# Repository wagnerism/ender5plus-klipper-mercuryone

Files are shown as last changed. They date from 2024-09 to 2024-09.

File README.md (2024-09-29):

# ender5plus-klipper-mercuryone
Klipper configurations for Ender 5 Plus with MKS Robin Nano v3 and the Mercury One CoreXY mod.

# Future changes
* Install Rapido UHF hotend<br>
https://trianglelab.net/products/rapido-hotend-20?VariantsId=11312
* Install filament runout detector direct on the orbiter extruder<br>
https://trianglelab.net/products/orbiter-v2-filament-sensor?VariantsId=10610
* Hydra 3-point bed mod
  * https://docs.zerog.one/manual/build/hydra/introduction
  * second MCU instead of replacing the main board with one that has more stepper drivers

# References

## Hardware I Used

| **Item** | **Name** | **Link** | **Note** |
|-|-|-|-|
| **Base Printer** | Ender 5 Plus| https://www.creality.com/products/ender-5-plus-3d-printer||
| **CoreXY Mod** | Mercury One Zero G| https://docs.zerog.one/||
| **Mainboard** | MKS Robin Nano V3.1| https://github.com/makerbase-mks/MKS-Robin-Nano-V3| |
| **Probe**| BTT Microprobe| https://github.com/bigtreetech/MicroProbe||
| **Hotend**| Triangle Lab Rapido HF| https://trianglelab.net/products/rapido-hotend?VariantsId=10027| Changing to Rapido UHF|
| **Extruder**| Triangle Lab Orbiter v2 | https://trianglelab.net/products/orbiter-extruder-v20%EF%BC%88black-gear%EF%BC%89 ||
| **Filament Sensor** | BTT Smart Filament Sensor | https://github.com/bigtreetech/smart-filament-detection-module | Changing to Orbiter detector|
| **E34M1**|EVA3 for Mercury One| https://jon-harper.github.io/E34M1/||
| **stepper motors**|Mercury One BOM|https://www.omc-stepperonline.com/e-series-nema-17-bipolar-55ncm-77-88oz-in-2a-42x48mm-4-wires-w-1m-cable-connector-17he19-2004s||

## My Contribution
STL file: Mount the BTT Microprobe on the E34M1 head (uses M3 bolts and nuts)

## Software / Documentation
| **Name** | **Link** | **Note** |
|---|---|---|
| **KIAUH** | https://github.com/dw-0/kiauh?tab=readme-ov-file||
| **TMC Autotuning** | https://github.com/andrewmcgr/klipper_tmc_autotuneGuide** ||
| **Ellis' Tuning Guide** | https://ellis3dp.com/Print-Tuning-Guide/||
| **Ellis' TEST_SPEED macro** | https://github.com/AndrewEllis93/Print-Tuning-Guide/blob/main/macros/TEST_SPEED.cfg  ||

# Custom configuration changes
Using the MKS Robin Nano's unused second extruder ports.

## Dual Z
The "hotend 1" stepper driver is being used for stepper_z1. Z_TILT_ADJUST requires that the stepper motors be connected a specific way.<br><br>With origin at the front-left corner:
* Connect the first/original stepper_z driver to the left-hand stepper motor.
* Connect the second/hotend1 stepper_z1 driver to the right-hand stepper motor.

## Fans
The Ender 5 Plus has three fans - hotend, part cooling, and controller. None of them are "always-on."

| **Connector**|**MCU Pin**| **Device** |
|---|---|----|
| FAN1 | PC14 | controller/case fan
| FAN2 | PB1 | hotend fan
| HE1 | PB0 | part cooling fan(s)

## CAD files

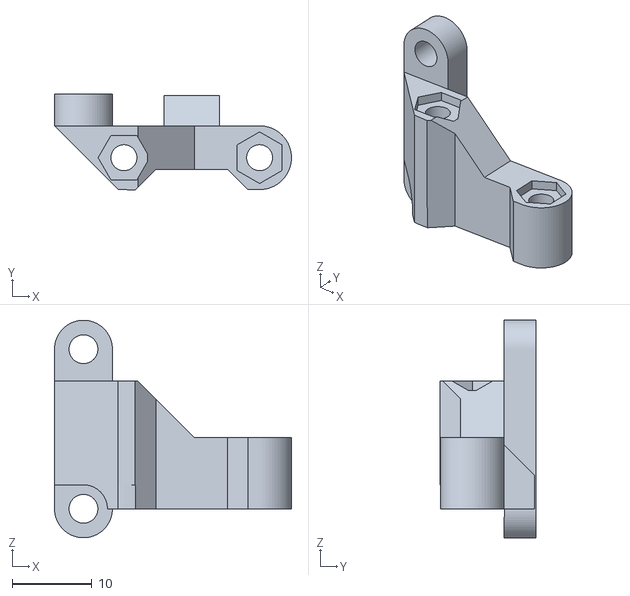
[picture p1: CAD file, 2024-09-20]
E34M1 MercuryOne BTT micro probe mount with Rapido HF.stl
29.7 x 12.1 x 27.3

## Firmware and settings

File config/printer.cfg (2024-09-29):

[include fluidd.cfg]
[include tuning/TEST_SPEED.cfg]
[include slicer_macros/orcaslicer.cfg]
[include macros.cfg]
#[include filament_sensor.cfg]
[include filament_macros.cfg]

[exclude_object]

# TODOs 
# camera
# beeper on PC5
# end print macro to retract, move to 0,0 , move z down some
# first layer https://ellis3dp.com/Print-Tuning-Guide/articles/first_layer_squish.html Z_OFFSET_APPLY_PROBE

[virtual_sdcard]
path: /home/rfwagner/printer_data/gcodes
on_error_gcode: CANCEL_PRINT
[mcu]
serial: /dev/serial/by-id/usb-Klipper_stm32f407xx_2C0043000950313154393520-if00

[display_status]
[pause_resume]

[printer]
kinematics: corexy
max_velocity: 800  
max_accel: 10000 
# minimum_cruise_ratio: 0.5
max_z_velocity: 5
max_z_accel: 100
square_corner_velocity: 5.0
# Enable arcs support
[gcode_arcs]
resolution: 0.1


[temperature_sensor MCU]
sensor_type: temperature_mcu
[temperature_sensor RPi]
sensor_type: temperature_host



[mcu rpi]
serial: /tmp/klipper_host_mcu

[adxl345]
cs_pin: rpi:None

[resonance_tester]
accel_chip: adxl345
probe_points:
    170, 170, 5  # an example



[input_shaper]
#shaper_freq_x: 53.4
#shaper_type_x: mzv
#shaper_freq_y: 48.0
#shaper_type_y: 3hump_ei



[autotune_tmc stepper_x]
motor: omc-17he19-2004s
#tuning_goal: silent  # default: auto=performance
##extra_hysteresis: 0  # up to 8, reduce hum/vib at low speeds
[stepper_x]
# StepperOnline 17HE19-2004S rated at 2.0A max
# https://www.omc-stepperonline.com/e-series-nema-17-bipolar-55ncm-77-88oz-in-2a-42x48mm-4-wires-w-1m-cable-connector-17he19-2004s
# max current 2.0A
step_pin: PE3
dir_pin: !PE2
enable_pin: !PE4
endstop_pin: !PA15
rotation_distance: 40
microsteps: 16
full_steps_per_rotation: 200
position_min: 0
position_endstop: 377 
position_max: 377
homing_speed: 125 #50
homing_retract_dist: 10
[tmc2209 stepper_x]
uart_pin: PD5
run_current: 1.13 # 1.13  # max current 2.0A https://docs.zerog.one/universal/klippercalculator
interpolate: true



[autotune_tmc stepper_y]
motor: omc-17he19-2004s
#tuning_goal: silent  # default: auto=performance
##extra_hysteresis: 0  # up to 8, reduce hum/vib at low speeds
[stepper_y]
# StepperOnline 17HE19-2004S rated at 2.0A max
step_pin: PE0
dir_pin: !PB9
enable_pin: !PE1
endstop_pin: !PD2
rotation_distance: 40
microsteps: 16
full_steps_per_rotation: 200 
position_min: 0
position_endstop: 348 
position_max: 353
homing_speed: 125 #50
homing_retract_dist: 10
[tmc2209 stepper_y]
uart_pin: PD7
run_current: 1.13 # 1.13  # max current 2.0A https://docs.zerog.one/universal/klippercalculator
interpolate: true



[autotune_tmc stepper_z]
motor: creality-42-34
tuning_goal: auto  # default auto=silent
[stepper_z]  # https://github.com/Klipper3d/klipper/blob/master/config/printer-creality-ender5plus-2019.cfg
# Creality 42-34 rated at 1.5A max
# left hand side
step_pin: PB5
dir_pin: !PB4
enable_pin: !PB8
microsteps: 16
rotation_distance: 4
endstop_pin: probe:z_virtual_endstop
position_max: 410
position_min: -10.0
homing_speed: 10.0
[tmc2209 stepper_z]
uart_pin: PD4
run_current: 0.75 # 0.85  # max current 1.5A https://docs.zerog.one/universal/klippercalculator
interpolate: true



[autotune_tmc stepper_z1]
motor: creality-42-34
tuning_goal: auto  # default auto=silent
[stepper_z1]
# Creality 42-34 rated at 1.5A
# right hand side
step_pin: PD15
dir_pin: !PA1 
enable_pin: !PA3 
microsteps: 16
rotation_distance: 4
[tmc2209 stepper_z1]
uart_pin: PD8
run_current: 0.75 # 0.85  # max current 1.5A https://docs.zerog.one/universal/klippercalculator
interpolate: true

[safe_z_home]
home_xy_position: 175,175
z_hop: 5

[z_tilt]
z_positions:    -19,165
                395,165
points:         31,174
                377,174
speed: 300

[screws_tilt_adjust]
screw1: 66,43
screw1_name: front_left
screw2: 358,43
screw2_name: front_right
screw3: 358,304
screw3_name: rear_right
screw4: 66,304
screw4_name: rear_left
screw_thread: CW-M3
speed: 500



[autotune_tmc extruder]
motor: ldo-36sth20-1004ahg
tuning_goal: performance  # default auto=silent
[extruder]
# orbiter extruder v2.0 LDO  https://trianglelab.net/u_file/2112/11/file/Orbiterv20FirmwareConfiguration-031c.pdf
# 690 steps/mm @ 16 micro-stepping
# motor current 1.2A peak or 0.85A RMS LDO-36STH20-1004AHG
# max accelleration 10000 mm/s2
# Triangle Lab Rapido HF
step_pin: PD6
dir_pin: !PD3
enable_pin: !PB3
microsteps: 16
full_steps_per_rotation: 200  # per TriangleLab doc
rotation_distance: 4.637  # per TriangleLab doc
nozzle_diameter: 0.600
filament_diameter: 1.750
max_extrude_only_distance: 500
max_extrude_only_velocity: 120
pressure_advance: 0.025
pressure_advance_smooth_time: 0.03
heater_pin: PE5
sensor_type: ATC Semitec 104NT-4-R025H42G
sensor_pin: PC1
#control: pid
#pid_Kp: 14.669
#pid_Ki: 0.572
#pid_Kd: 94.068
min_temp: 0
max_temp: 280
[tmc2209 extruder]
uart_pin: PD9
run_current: 0.85
hold_current: 0.100
sense_resistor: 0.11 
driver_TBL: 0
driver_HEND: 6
driver_HSTRT: 7
driver_TOFF: 4
interpolate: true



[heater_bed]
heater_pin: PA0
sensor_type: EPCOS 100K B57560G104F
sensor_pin: PC0
#control: pid
#pid_Kp: 325.10
#pid_Ki: 63.35
#pid_Kd: 417.10
min_temp: 0
max_temp: 130



[fan]  # print cooling fan
# originally pin: PC14   # fan1 without hardware PWM
pin: PB0  # "he1" repurposed connection
# yel/blu wires to head
[heater_fan heatbreak_cooling_fan]  
pin: PB1 # fan2 with hardware PWM
# red/blk wires to head
[controller_fan controller_fan]
pin: PC14  # "fan1" repurposed connection
stepper: stepper_x, stepper_y, stepper_z, stepper_z1, extruder
# red/blk wires to case

# fan testing configurations
#[fan_generic he1_PB0_printfan]
#pin: PB0  # yel/blu wires to head
## SET_FAN_SPEED FAN=he1_PB0_printfan SPEED=100

#[fan_generic fan2_PB1_heatbreak]
#pin:PB1  # red/blk wires to head
## SET_FAN_SPEED FAN=fan2_PB1_heatbreak SPEED=100

#[fan_generic fan1_PC14_controller]
#pin: PC14 # red/blk wires to case
## SET_FAN_SPEED FAN=fan1_PC14_controller SPEED=100


# https://github.com/bigtreetech/MicroProbe
[gcode_macro PROBE_DOWN]
gcode:
    SET_PIN PIN=probe_enable VALUE=1
[gcode_macro PROBE_UP]
gcode:
    SET_PIN PIN=probe_enable VALUE=0
[output_pin probe_enable]
pin: PA8  # Set to the control pin on your board
value: 0
[probe]
pin: ^!PC8  # for v2 microprobe
deactivate_on_each_sample: False
x_offset: -24
y_offset: -9
#z_offset: 2.05
samples: 2
samples_tolerance: 0.05
samples_tolerance_retries: 3
activate_gcode:
    PROBE_DOWN
    G4 P500
deactivate_gcode:
    PROBE_UP


[bed_mesh]
# 44,9 yields 68,18 at first point
# refers to probe location offset is -24, -9
speed: 500
horizontal_move_z: 2
mesh_min: 20, 0
mesh_max: 352, 321
probe_count: 7, 7
mesh_pps: 2, 2
algorithm: bicubic
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

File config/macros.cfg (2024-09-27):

[gcode_macro CALIBRATE_SHAPER]
gcode:  _CG28
        SHAPER_CALIBRATE

#[gcode_macro SAVE]
#gcode:  

[gcode_macro _CG28]
gcode:
    {% if "xyz" not in printer.toolhead.homed_axes %}
        G28
    {% endif %}

#https://ellis3dp.com/Print-Tuning-Guide/articles/index_useful_macros.html
[gcode_macro DUMP_VARIABLES]
gcode:
    {% set filter_name = params.NAME|default('')|string|lower %}
    {% set filter_value = params.VALUE|default('')|string|lower %}
    {% set show_cfg = params.SHOW_CFG|default(0)|int %}
    
    {% set out = [] %}

    {% for key1 in printer %}
        {% for key2 in printer[key1] %}
            {% if (show_cfg or not (key1|lower == 'configfile' and key2|lower in ['config', 'settings'])) and (filter_name in key1|lower or filter_name in key2|lower) and filter_value in printer[key1][key2]|string|lower %}
                {% set dummy = out.append("printer['%s'].%s = %s" % (key1, key2, printer[key1][key2])) %}
            {% endif %}
        {% else %}
            {% if filter_name in key1|lower and filter_value in printer[key1]|string|lower %}
                {% set dummy = out.append("printer['%s'] = %s" % (key1, printer[key1])) %}
            {% endif %}
        {% endfor %}
    {% endfor %}
    
    {action_respond_info(out|join("\n"))}

[gcode_macro GET_VARIABLE]
gcode:
    {% set names = (params.NAME).split('.')|list %}
    {% set join = (params.JOIN)|default(1)|int %}
    
    {% set _dummy0 = namespace( break = 0 ) %}
    {% set _dummy1 = namespace( out = printer[names|first] ) %}
    
    {% for name in names if _dummy0.break == 0 %}
        {% if loop.index > 1 %}
            {% if name in _dummy1.out %}
                {% set _dummy1.out = _dummy1.out[name] %}
            {% elif name[0] in '0123456789' and _dummy1.out is iterable and _dummy1.out is not string and _dummy1.out is not mapping and _dummy1.out|length > name[0]|int %}
                {% set _dummy1.out = _dummy1.out[name|int] %}
            {% else %}
                {% set _dummy0.break = loop.index0 %}
            {% endif %}
        {% endif %}
    {% endfor %}
    
    {% if _dummy1.out is boolean %}
        { action_respond_info('Type: boolean') }
    {% elif _dummy1.out is float %}
        { action_respond_info('Type: float') }
    {% elif _dummy1.out is integer %}
        { action_respond_info('Type: integer') }
    {% elif _dummy1.out is mapping %}
        { action_respond_info('Type: mapping') }
    {% elif _dummy1.out is string %}
        { action_respond_info('Type: string') }
    {% elif _dummy1.out is iterable %}
        { action_respond_info('Type: iterable') }
    {% elif _dummy1.out is none %}
        { action_respond_info('Type: none') }
    {% elif _dummy1.out is undefined %}
        { action_respond_info('Type: undefined') }
    {% elif _dummy1.out is callable %}
        { action_respond_info('Type: callable') }
    {% else %}
        { action_respond_info('Type: unknown') }
    {% endif %}
    
    {% if join and _dummy1.out is iterable and _dummy1.out is not string and _dummy1.out is not mapping %}
        { action_respond_info('%s' % _dummy1.out|join("\n")) }
    {% else %}
        { action_respond_info('%s' % _dummy1.out) }
    {% endif %}
    
    {% if _dummy0.break != 0 %}
        { action_respond_info('"printer.%s" does not contain "%s"!' % (names[0:_dummy0.break]|join('.'), names[_dummy0.break])) }
    {% endif %}

[gcode_macro PAUSE]
rename_existing: BASE_PAUSE
gcode:
    # Parameters
    {% set z = params.Z|default(10)|int %}                                                   ; z hop amount

    {% if printer['pause_resume'].is_paused|int == 0 %}
        SET_GCODE_VARIABLE MACRO=RESUME VARIABLE=zhop VALUE={z}                              ; set z hop variable for reference in resume macro
        SET_GCODE_VARIABLE MACRO=RESUME VARIABLE=etemp VALUE={printer['extruder'].target}    ; set hotend temp variable for reference in resume macro

        SET_FILAMENT_SENSOR SENSOR=filament_sensor ENABLE=0                                  ; disable filament sensor
        SAVE_GCODE_STATE NAME=PAUSE                                                          ; save current print position for resume
        BASE_PAUSE                                                                           ; pause print
        {% if (printer.gcode_move.position.z + z) < printer.toolhead.axis_maximum.z %}       ; check that zhop doesn't exceed z max
            G91                                                                              ; relative positioning
            G1 Z{z} F900                                                                     ; raise Z up by z hop amount
        {% else %}
            { action_respond_info("Pause zhop exceeds maximum Z height.") }                  ; if z max is exceeded, show message and set zhop value for resume to 0
            SET_GCODE_VARIABLE MACRO=RESUME VARIABLE=zhop VALUE=0
        {% endif %}
        G90                                                                                  ; absolute positioning
        G1 X{printer.toolhead.axis_maximum.x/2} Y{printer.toolhead.axis_minimum.y+5} F6000   ; park toolhead at front center
        SAVE_GCODE_STATE NAME=PAUSEPARK                                                      ; save parked position in case toolhead is moved during the pause (otherwise the return zhop can error)
        M104 S0                                                                              ; turn off hotend
        SET_IDLE_TIMEOUT TIMEOUT=43200                                                       ; set timeout to 12 hours
    {% endif %}

[gcode_macro RESUME]
rename_existing: BASE_RESUME
variable_zhop: 0
variable_etemp: 0
gcode:
    # Parameters
    {% set e = params.E|default(2.5)|int %}                                          ; hotend prime amount (in mm)

    {% if printer['pause_resume'].is_paused|int == 1 %}
        SET_FILAMENT_SENSOR SENSOR=filament_sensor ENABLE=1                          ; enable filament sensor
        #INITIAL_RGB                                                                    ; reset LCD color
        SET_IDLE_TIMEOUT TIMEOUT={printer.configfile.settings.idle_timeout.timeout}  ; set timeout back to configured value
        {% if etemp > 0 %}
            M109 S{etemp|int}                                                        ; wait for hotend to heat back up
        {% endif %}
        RESTORE_GCODE_STATE NAME=PAUSEPARK MOVE=1 MOVE_SPEED=100                     ; go back to parked position in case toolhead was moved during pause (otherwise the return zhop can error)
        G91                                                                          ; relative positioning
        M83                                                                          ; relative extruder positioning
        {% if printer[printer.toolhead.extruder].temperature >= printer.configfile.settings.extruder.min_extrude_temp %}
            G1 Z{zhop * -1} E{e} F900                                                ; prime nozzle by E, lower Z back down
        {% else %}
            G1 Z{zhop * -1} F900                                                     ; lower Z back down without priming (just in case we are testing the macro with cold hotend)
        {% endif %}
        RESTORE_GCODE_STATE NAME=PAUSE MOVE=1 MOVE_SPEED=60                          ; restore position
        BASE_RESUME                                                                  ; resume print
    {% endif %}
[gcode_macro CANCEL_PRINT]
rename_existing: BASE_CANCEL_PRINT
gcode:
    SET_IDLE_TIMEOUT TIMEOUT={printer.configfile.settings.idle_timeout.timeout} ; set timeout back to configured value
    CLEAR_PAUSE
    SDCARD_RESET_FILE
    PRINT_END
    BASE_CANCEL_PRINT

[gcode_macro M600]
gcode:
    #LCDRGB R=0 G=1 B=0  ; Turn LCD green
    PAUSE                ; Pause

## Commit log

2024-09-27 after first successful print
    [TEST_SPEED.cfg, filament_macros.cfg, filament_sensor.cfg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]
2024-09-29 minor cleanup
    [printer.cfg]
